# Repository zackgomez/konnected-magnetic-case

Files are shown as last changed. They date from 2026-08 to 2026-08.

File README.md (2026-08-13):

# Konnected Alarm Panel Pro Case — Magnetic Mount Remix

**On Printables:** https://www.printables.com/model/1809216-konnected-alarm-panel-pro-case-magnetic-mount-pres

A remix of [zefer's Konnected Alarm Panel Pro Case](https://www.printables.com/model/680613-konnected-alarm-panel-pro-case)
that mounts magnetically inside a steel alarm panel enclosure — no screws, no
standoff hardware, no drilling. Six cheap 6×3mm neodymium disc magnets
press-fit into pockets in the case base; the case snaps onto the
enclosure wall and pulls off by hand. A printed-in-place alternative to
[Konnected's magnetic standoffs](https://konnected.io/products/magnetic-standoffs)
that keeps the full protection of an enclosed case.

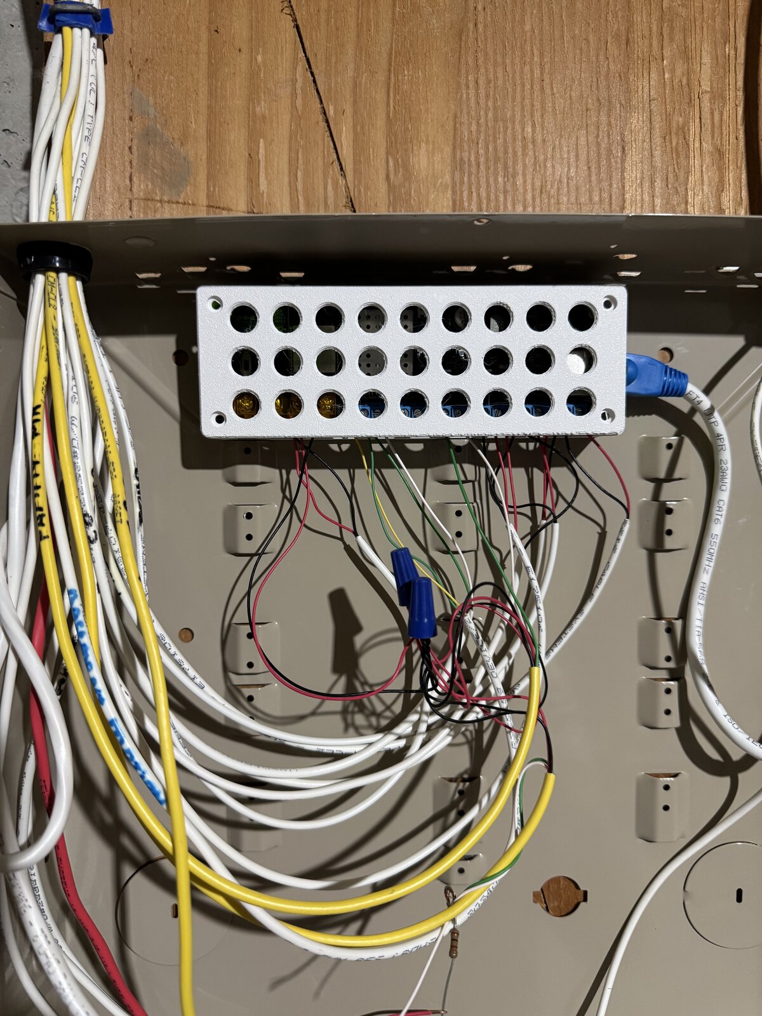
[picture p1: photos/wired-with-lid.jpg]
wired up in an alarm panel enclosure


Every zone wire stays landed while the panel lifts off the enclosure wall by
hand.

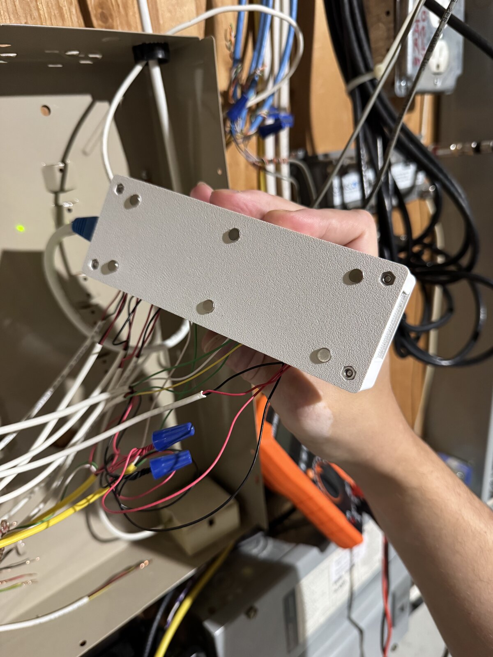
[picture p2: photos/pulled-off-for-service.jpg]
pulled off for service, wires still connected


## What changed from the original

- Six magnet pockets cut into the underside of the base floor: four corners
  (±58, ±17) plus a mid-span pair (0, ±17) — a 116 × 34mm stance
- Each pocket: Ø6.20 × 2.45mm (magnet sits ~0.2mm proud, so the case stands on
  the magnet faces), with a low Ø9mm ceiling pad inside the case and a Ø2.5mm
  vent hole — air/glue escape during insertion, and an eject port if you ever
  need to poke a magnet back out
- The two woodscrew wall-mount holes and their interior bosses are removed —
  this base mounts magnetically only (use the original if you want screws)
- Lid and board mounting are unchanged: zefer's lid is included verbatim
  (`konnected_lid.stl`), board mounts with his M3 nut/standoff/screw scheme

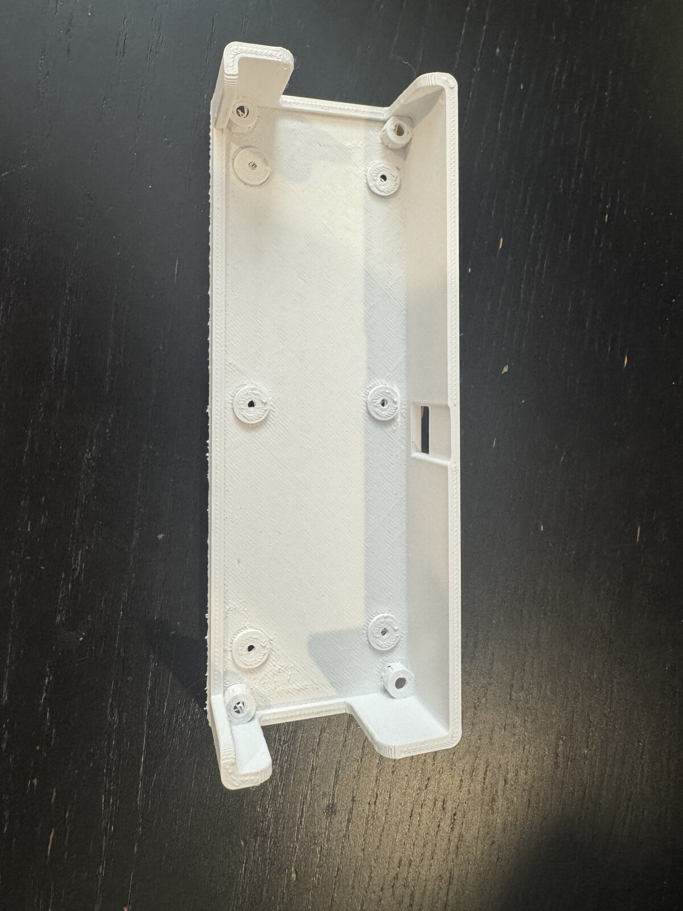
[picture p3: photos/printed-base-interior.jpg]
printed base interior: ceiling pads and vent holes


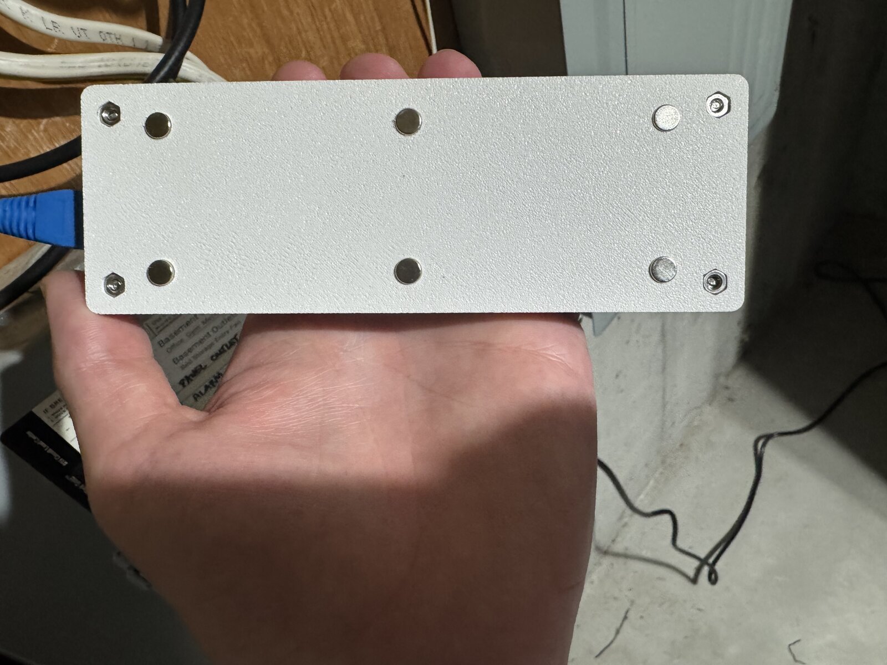
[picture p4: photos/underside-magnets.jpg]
underside with magnets seated


More photos in [`photos/`](photos/) (bare install, lid-off wiring); CAD renders
of both faces in [`previews/`](previews/).

## Bill of materials

- 6 × neodymium disc magnets, 6×3mm (mine calipered 6.03 × 2.64 — caliper
  yours). No polarity concerns against steel.
- CA glue (optional, see Assembly)
- Board mounting, per the original: 4 × M3 nuts, standoffs (e.g. M3×6+6), screws

## Printing & fit

The press-fit diameter depends on your printer's hole shrinkage, so
**print `magnet_fit_coupon.stl` first** (a few minutes, as imported — pockets
and dot marks face up) and press a magnet into each pocket. Dots 1–4 mark
Ø6.10 / 6.20 / 6.30 / 6.40 (1 = tightest). Pick the snug-but-fully-seatable
one; the vent hole lets you poke the magnet out and reuse it. If your winner
isn't Ø6.20, set `POCKET_D` in `build_remix.py` and regenerate (see below).

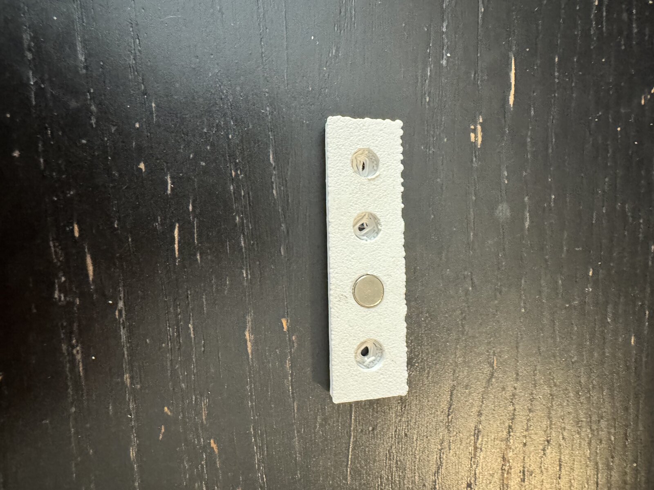
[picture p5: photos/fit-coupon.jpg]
fit coupon with a magnet seated


Then print `konnected_base_magnetic.stl` flat, no supports (pocket ceilings are
short bridges — they print fine). The pictured set is **ASA, 0.4 nozzle,
0.3mm layers** (~30g for base + lid); PLA at 0.2mm works too, per the original.

## Assembly

1. Press the six magnets in until seated. CA is optional — press fit alone
   holds mine; add a drop per pocket if magnets stay on the wall when you
   pull the case off.
2. Mount the board per the original case's instructions (M3 nuts in the corner
   pockets, standoffs, screws), add the lid.
3. Stick it to the inside of the enclosure.

**If your enclosure wall has raised obstructions** (screw joints, weld nubs,
rivets) that keep the magnets from reaching flat steel: stack a second disc
onto each installed magnet — they self-align magnetically; add a drop of CA
between. Each extra disc buys ~2.6mm of standoff, grip on the flat wall stays
full-strength, and nothing needs reprinting.

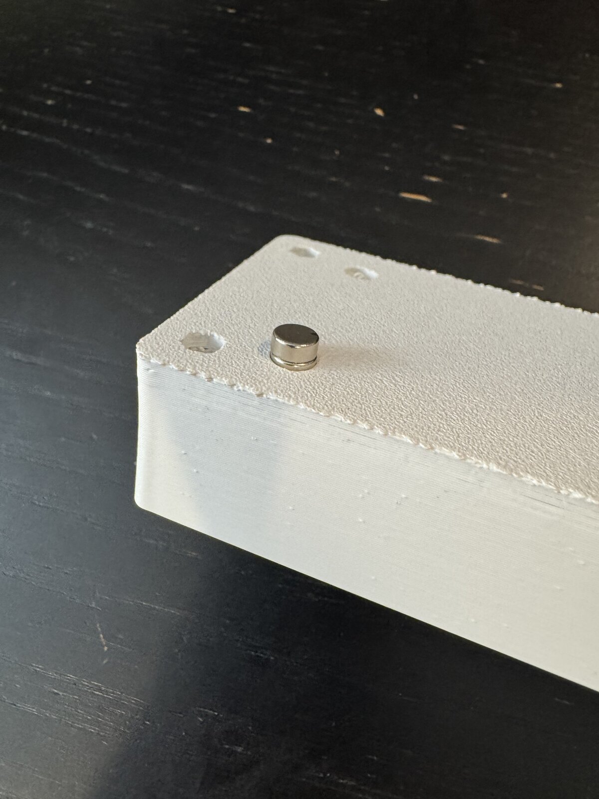
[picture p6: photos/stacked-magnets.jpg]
stacked magnet pair for extra standoff


## Regenerating the models

The geometry is script-built with [FreeCAD](https://www.freecad.org) (1.1.x)
from a STEP conversion of zefer's original base (included in `original/`):

```
freecadcmd build_remix.py    # -> konnected_base_magnetic.step + .stl
freecadcmd build_coupon.py   # -> magnet_fit_coupon.stl
```

All dimensions (station positions, pocket Ø/depth, pad, vent) are parameters at
the top of each script — different magnets are a two-line change.

## License & attribution

[CC-BY-SA 4.0](LICENSE), as a derivative of
[Konnected Alarm Panel Pro Case](https://www.printables.com/model/680613-konnected-alarm-panel-pro-case)
© zefer, CC-BY-SA 4.0. `konnected_lid.stl` is zefer's lid, unchanged; the
`original/` STEPs are format-shifted copies of his base and lid (from his
published .f3d) — all redistributed under the same license so the project
is self-contained and the build script is runnable.

Remix designed and scripted by [Claude](https://claude.com) (Claude Fable 5,
via Claude Code) working with Zack Gomez — geometry analysis, FreeCAD build
scripts, and the fit-coupon workflow were Claude's; magnets, calipers, printer,
and judgment were Zack's.

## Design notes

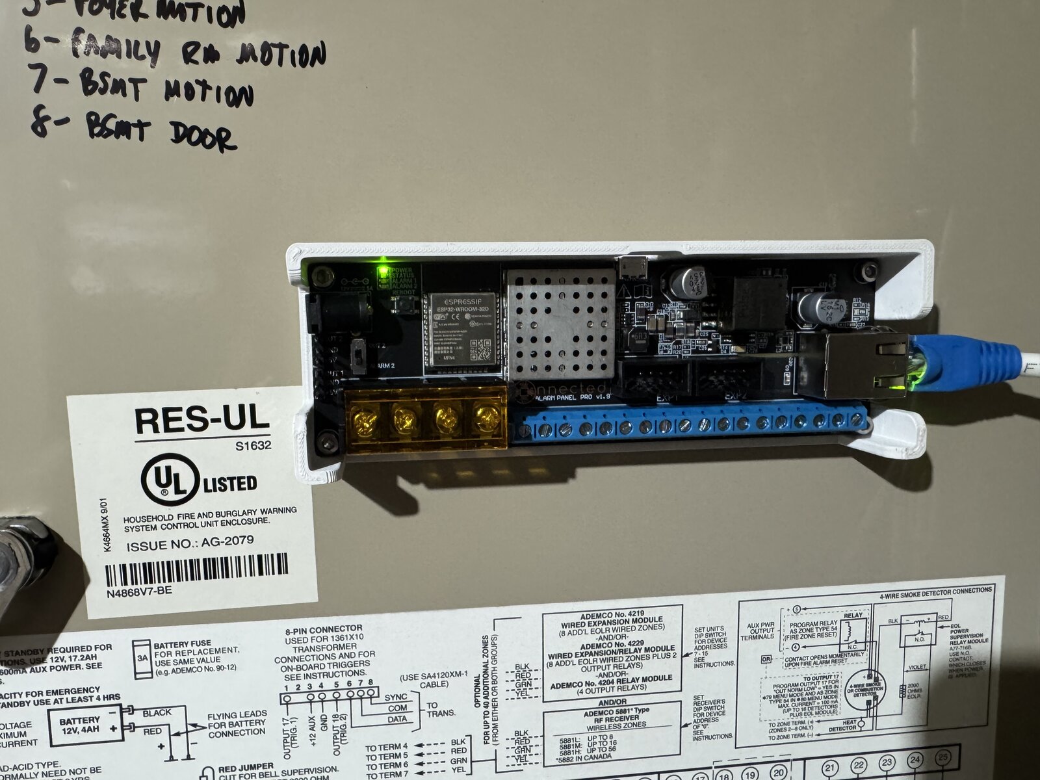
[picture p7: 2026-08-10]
photos/mounted-in-panel.jpg

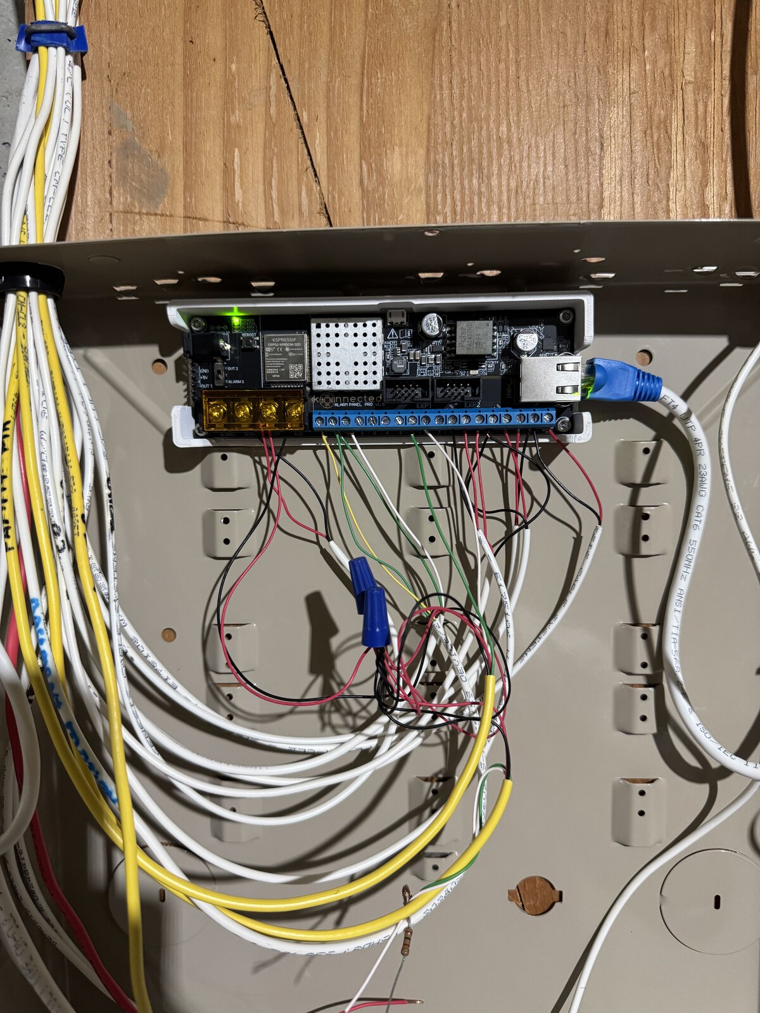
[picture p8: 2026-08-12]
photos/wired-no-lid.jpg

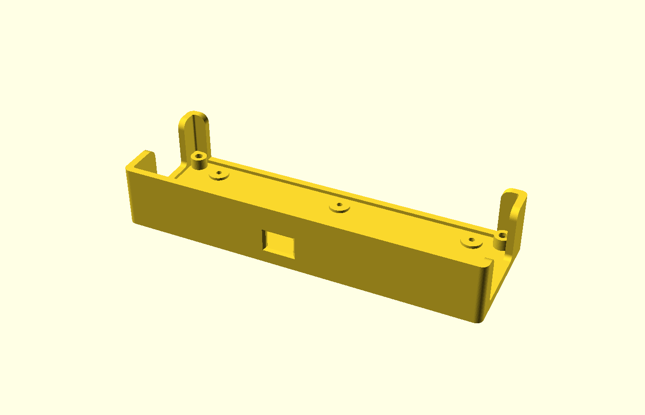
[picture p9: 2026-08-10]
previews/preview_top.png

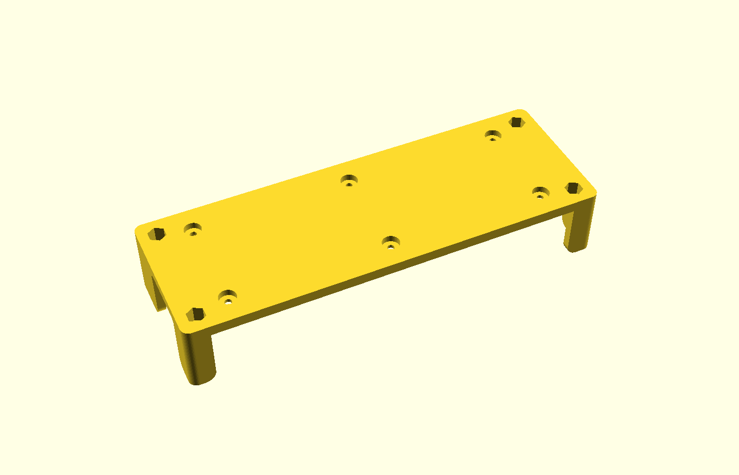
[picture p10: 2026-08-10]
previews/preview_bottom.png

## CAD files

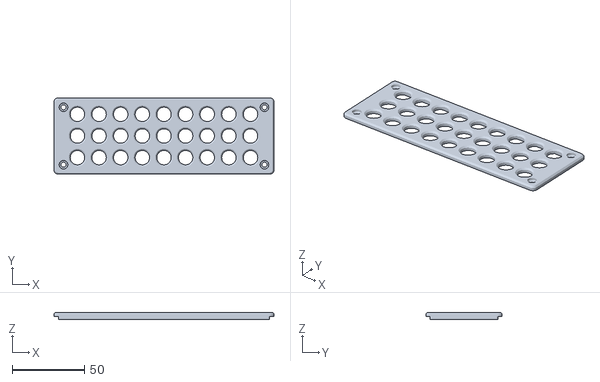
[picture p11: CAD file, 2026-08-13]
konnected_lid.stl
152.5 x 53.0 x 5.00

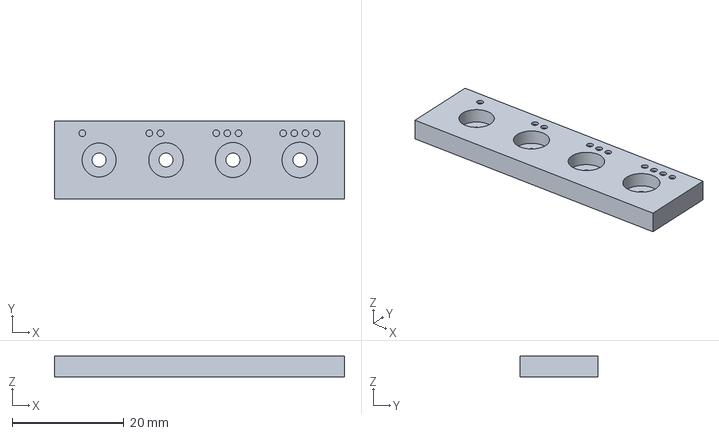
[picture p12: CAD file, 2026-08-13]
magnet_fit_coupon.step
52.0 x 14.0 x 3.70 mm

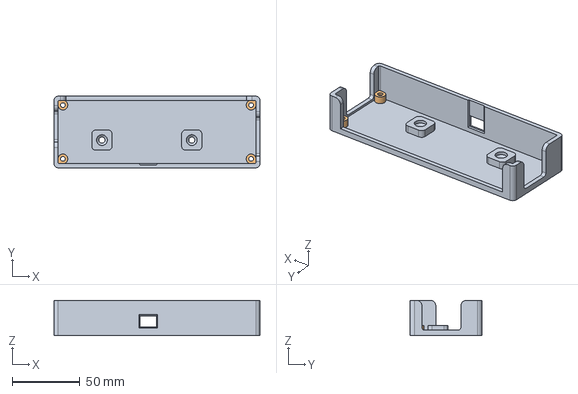
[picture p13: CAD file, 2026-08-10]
original/konnected_base_original.step
152.5 x 53.0 x 26.0 mm

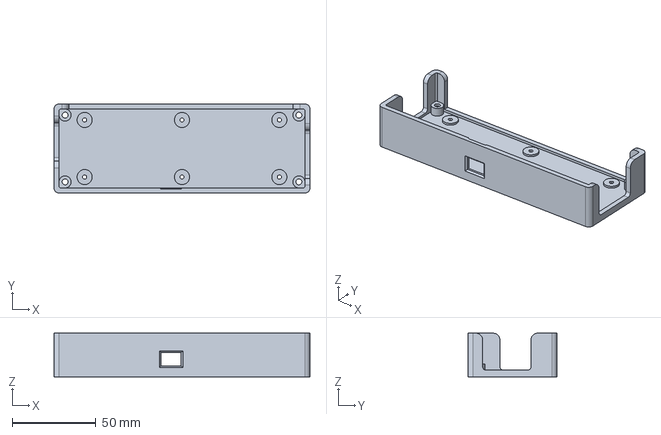
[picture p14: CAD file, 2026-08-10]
konnected_base_magnetic.step
152.5 x 53.0 x 26.0 mm

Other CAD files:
original/konnected_lid_original.step
konnected_base_magnetic.stl
magnet_fit_coupon.stl

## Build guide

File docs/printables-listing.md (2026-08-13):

# Printables upload package

Everything below is paste-ready. Files to upload are listed at the bottom.

**Publish as a remix** of zefer's model
(https://www.printables.com/model/680613-konnected-alarm-panel-pro-case) so
attribution links automatically.

## Title

Konnected Alarm Panel Pro Case — Magnetic Mount (press-fit magnets)

## Category / tags

Category: Hobby & Makers → Electronics (same as the original)
Tags: `konnected`, `alarm`, `alarm-panel`, `home-assistant`, `case`,
`magnetic`, `magnet`, `esphome`, `smart-home`, `freecad`, `asa`, `remix`

## Summary (120-char limit)

Remixed Konnected Alarm Panel Pro case replacing screw mounting with six
press-fit 6×3 mm magnets.

## Description

A remix of zefer's Konnected Alarm Panel Pro Case that mounts magnetically
inside a steel alarm enclosure: six 6×3 mm neodymium discs press-fit into
pockets in the base.

**Changes from the original:**

- Six magnet pockets (Ø6.20 × 2.45 mm) in the base underside; magnets sit
  ~0.2 mm proud, so the case stands on the magnet faces
- Each pocket: low ceiling pad inside, Ø2.5 mm vent hole (air escape on
  insertion, eject port for removal)
- Woodscrew wall-mount holes and their bosses removed — use the original if
  you want screws
- Lid (included verbatim) and board mounting unchanged

**Fit coupon included.** Press fit depends on your printer, so print
`magnet_fit_coupon.stl` first: four pockets at Ø6.10–6.40, dot-marked 1–4
(1 = tightest). Pick the snug-but-seatable one. Ø6.20 is the shipped STL;
other diameters are a one-line change in the FreeCAD script.

**Raised features on the enclosure wall** (screw joints, rivets) keeping the
magnets off flat steel? Stack a second disc on each magnet — self-aligning,
~2.6 mm more standoff per disc, full grip. The pictured install clears its
screw joints this way.

STEP files, parametric FreeCAD build scripts, and design notes:
https://github.com/zackgomez/konnected-magnetic-case

Designed and scripted in collaboration with Claude (Fable 5, via Claude
Code) — geometry analysis, build scripts, and the coupon workflow were
Claude's.

## Print settings

- Both parts print flat as exported, no supports (pocket ceilings are short
  bridges)
- As pictured: ASA, 0.4 mm nozzle, 0.3 mm layers, ~30 g for base + lid.
  PLA at 0.2 mm works too, per the original
- Coupon prints as imported: pockets and dot marks face up

## Assembly / hardware

- 6× neodymium disc magnets, 6×3 mm (mine calipered 6.03 × 2.64; no polarity
  concerns against steel)
- CA glue optional — press fit alone holds mine; add a drop per pocket if
  magnets stay on the wall when you pull the case off
- Board mounting per the original: 4× M3 nuts, standoffs (e.g. M3 6+6),
  M3 screws; lid screws M3×6

## Files to upload

STLs:
- `konnected_base_magnetic.stl` — the remixed base
- `konnected_lid.stl` — zefer's lid, unchanged
- `magnet_fit_coupon.stl` — fit-test coupon (print first)

STEPs (upload as "other files" for remixers):
- `konnected_base_magnetic.step`
- `magnet_fit_coupon.step`

Photos (from `photos/`):
- `pulled-off-for-service.jpg` — **cover image** (wired panel held mid-air:
  the whole point in one frame)
- `wired-with-lid.jpg` — finished install in the enclosure
- `wired-no-lid.jpg` — lid off, zones landed
- `mounted-in-panel.jpg` — first install, pre-wiring
- `underside-magnets.jpg` — magnets seated, bench
- `fit-coupon.jpg` — coupon with a magnet seated
- `stacked-magnets.jpg` — stacked pair for extra standoff
- `printed-base-interior.jpg` — ceiling pads and vent holes

Renders (from `previews/`, optional):
- `preview_bottom.png` — pocket layout
- `preview_top.png` — interior

License: **CC BY-SA 4.0** — required, inherited from the original
(ShareAlike). Publishing as a remix on Printables sets attribution up
automatically.

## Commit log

2026-08-10 Magnetic mount remix of zefer's Konnected Alarm Panel Pro case
    Six press-fit magnet pockets (6x2.6mm discs) in the base underside,
    woodscrew wall-mount features removed, plus a fit-test coupon and the
    FreeCAD scripts that generate both models from the original STEP.
    [konnected_base_magnetic.step, konnected_base_magnetic.stl, konnected_base_original.step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]
2026-08-10 Document magnet stacking for enclosures with raised obstructions
2026-08-12 Add wired-install photos; lead with the tool-free service shot
2026-08-12 Fix coupon to print as imported (pockets up); ASA print notes; coupon, stacking, and interior photos
    [magnet_fit_coupon.stl]
2026-08-12 Add paste-ready Printables listing draft
2026-08-13 Tighten listing and README: 6x3 magnets, CA optional, drop WiFi caveat
2026-08-13 Add coupon STEP export; list STEPs in upload manifest
    [magnet_fit_coupon.step]
2026-08-13 Include zefer's lid (STL + STEP) so the project is self-contained
    [konnected_lid.stl, konnected_lid_original.step]
2026-08-13 Link the Printables listing
